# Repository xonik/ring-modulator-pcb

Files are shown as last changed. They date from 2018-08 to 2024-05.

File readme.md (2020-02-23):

# Yusynth Ring modulator

http://yusynth.net/Modular/EN/RINGMOD/index.html

All text is from Yusynth

## Description

The balanced modulator or four quadrant multiplier, is a great classical module. it provides the same functions as those of a ring modulator. Its main purpose is to generate  sounds with a complex overtone content such as bell sounds and other klang tones !
The principle of this circuit is based on a Gilbert cell (see references at the end of this page) contained in the classical LM1496 IC.

Basically, if one feeds the A input with a sinewave with frequency f1, that is sin(2πf1), and the B input with a sinewave with frequenc f2, that is sin(2πf2), one gets at the output the product these two signals, that is sin(2πf1) x sin(2πf2).

Due to trigonomic properties it reads :

 sin(2πf1) x sin(2πf2) = sin(2π(f1+f2)) + sin(2π(f1-f2))

in other words the output is a mixture of two sinewaves, one with frequency f1+f2 and the other with frequency f1-f2.

## Schematic

The schematic of this balanced modulator is directly inspired by that of the Elektor's Formant  (which is a mere adaptation of the application schematic of the LM1496 datasheet, see at the end of this page). I have only changed the values of the input resistors in order to make the input signal levels compatible with the Moog/Dotcom standards (10V peak to peak) I also added an output stage that amplifies the output signal by 6.8 in order to obtain 10Vpp.

## Settings and trimming

There are four trimmers to adjust : A1 to A4. These trimmers are used for cancelling the input signals. The settings are quite simple, you will need a signal generator that delivers a sinewave signal with a 10V (peak to peak) output amplitude. Here is how to proceed :
Tune the generator on 1000Hz and set the output level of the generator to 10Vpp.

Connect the output AxB (or CxD) of the module to an audio amplifier. Be sure to set the input potentiometer of the amplifier to a low value : the output level of the module is 10Vpp and most of the audio amplifiers expect an input level that doesn't exceed 1Vpp.
Connect the signal generator to the input A (or C) with a capacitor (AC-INPUT). There, you must hxear the 1000Hz signal at the output AxB (or CxD).

Adjust the trimmer A2 (or A4) such that the 1000Hz signal can no longer be heard at the output.

Disconnect the signal generator from input A (or C) and then connect the signal generator to the input B (or D)  with a capacitor (AC-INPUT). There, you must hear the 1000Hz signal at the output AxB (or CxD).
Adjust the trimmer A1 (or A3) such that the 1000Hz signal can no longer be heard at the output.

Now the module is ready to operate. A last check can be done by connecting the 1000Hz signal to both inputs A and B (AC inputs) : there you must hear a single signal of frequency twice as high (2000Hz).

**Comment (JT): A1 and A3 are the 470/500 ohm pots, A2 and A4 are 200/220 ohm.**

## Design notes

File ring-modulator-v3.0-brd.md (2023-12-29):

# ring-modulator-v3.0

### Board top
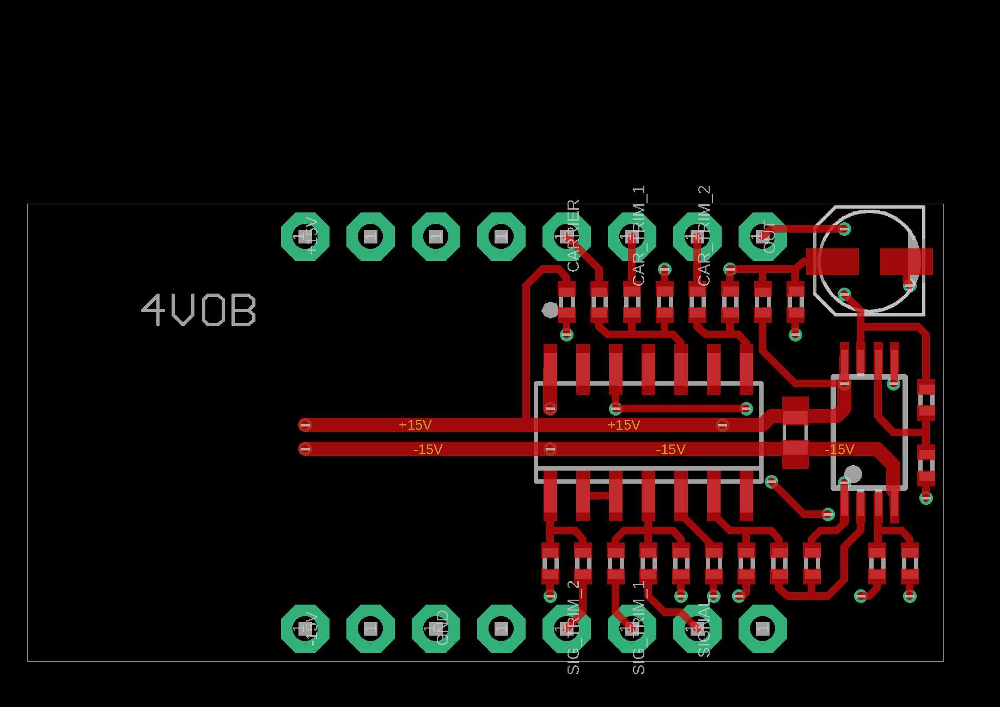
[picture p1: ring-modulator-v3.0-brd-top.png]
Top side

### Board bottom
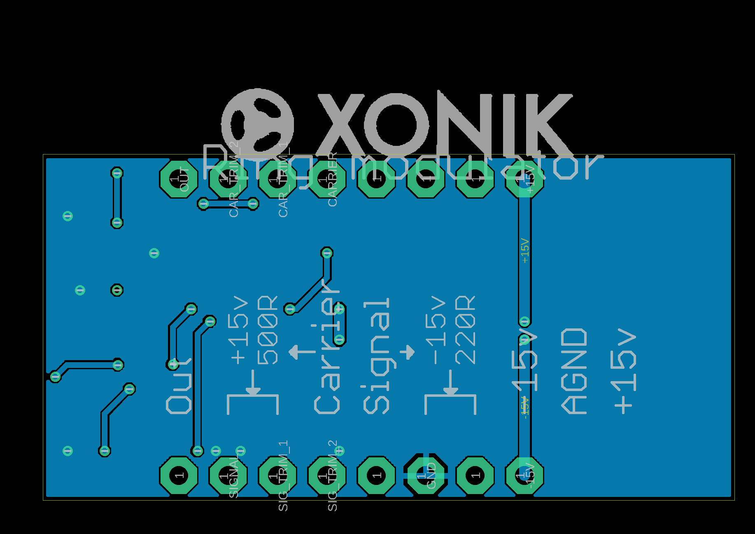
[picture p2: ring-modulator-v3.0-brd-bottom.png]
Bottom side


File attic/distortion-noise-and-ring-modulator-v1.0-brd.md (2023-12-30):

# distortion-noise-and-ring-modulator-v1.0

### Board top
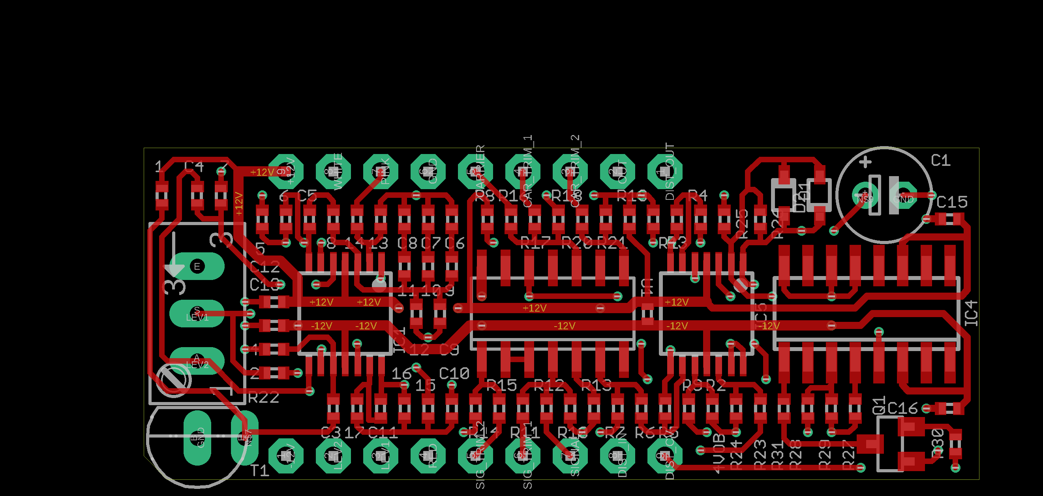
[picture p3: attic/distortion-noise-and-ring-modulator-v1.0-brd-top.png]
Top side

### Board bottom
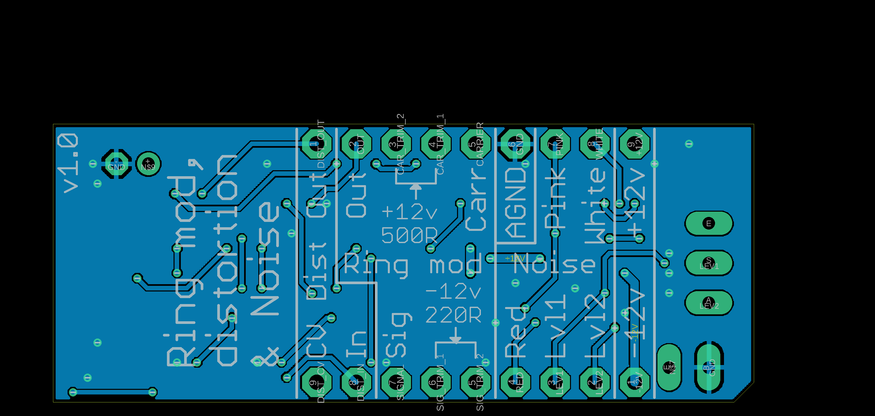
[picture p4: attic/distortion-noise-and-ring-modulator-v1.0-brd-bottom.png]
Bottom side


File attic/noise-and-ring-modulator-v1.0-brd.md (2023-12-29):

# noise-and-ring-modulator-v1.0

### Board top
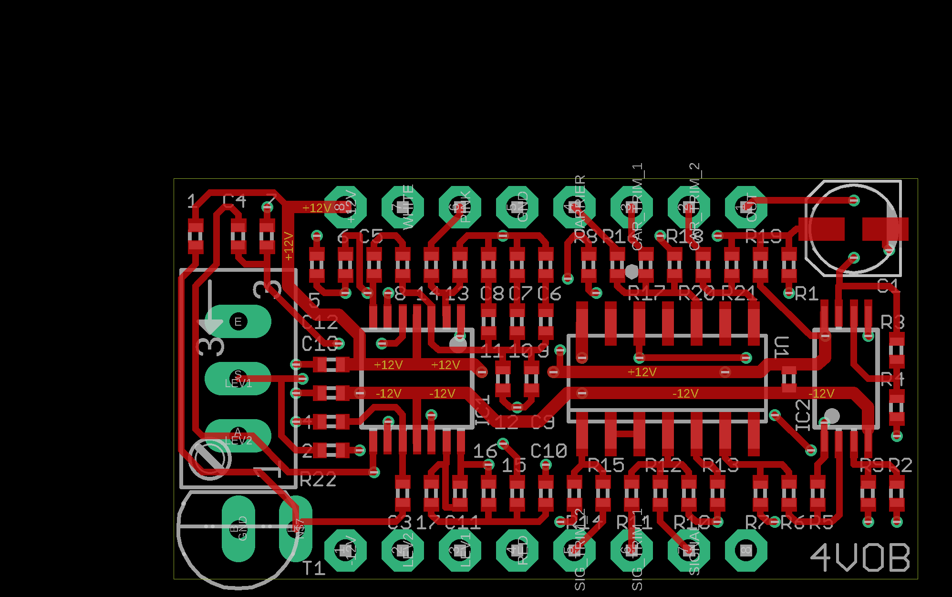
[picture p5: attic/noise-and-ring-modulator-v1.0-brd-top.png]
Top side

### Board bottom
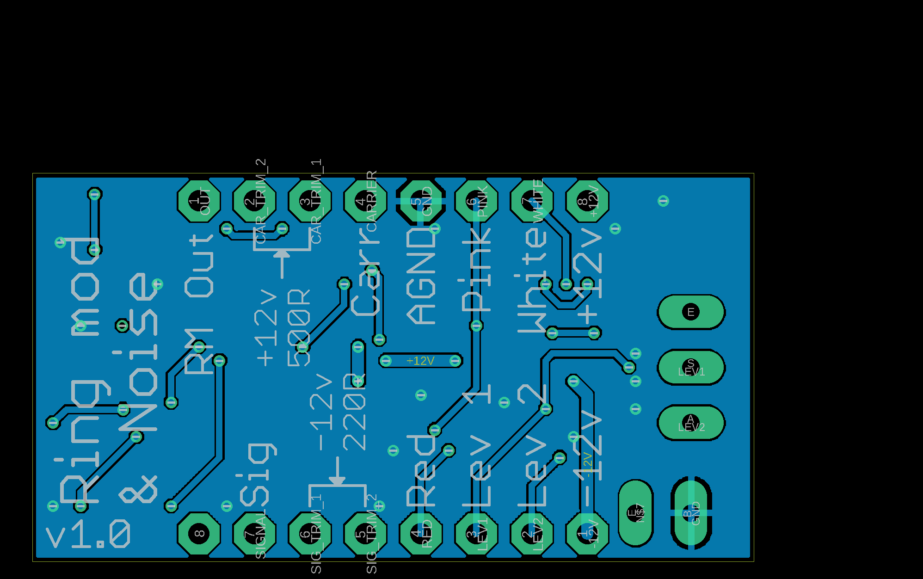
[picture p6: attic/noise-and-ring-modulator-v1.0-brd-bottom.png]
Bottom side


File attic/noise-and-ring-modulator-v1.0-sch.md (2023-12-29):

# noise-and-ring-modulator-v1.0

### Sheet 1

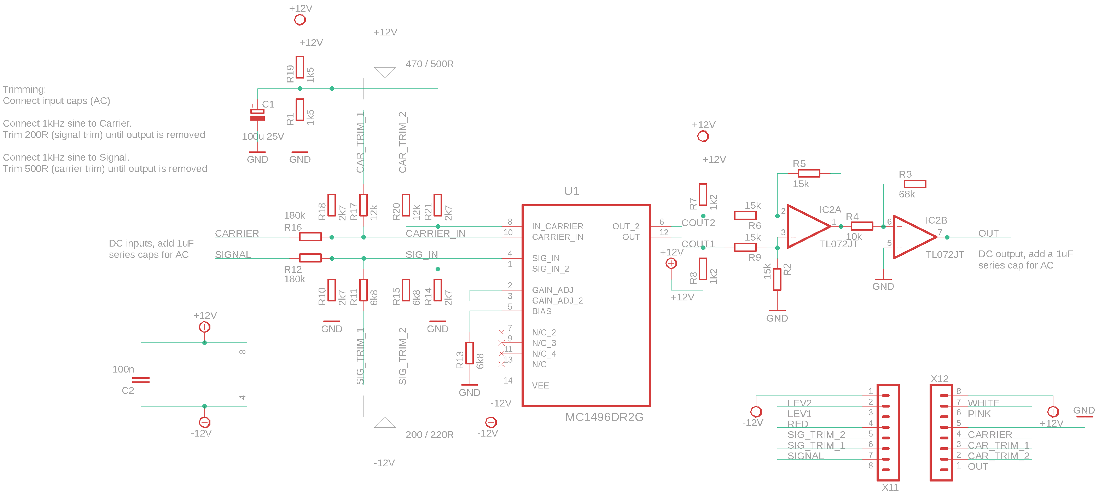
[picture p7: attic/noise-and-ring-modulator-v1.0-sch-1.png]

### Sheet 2

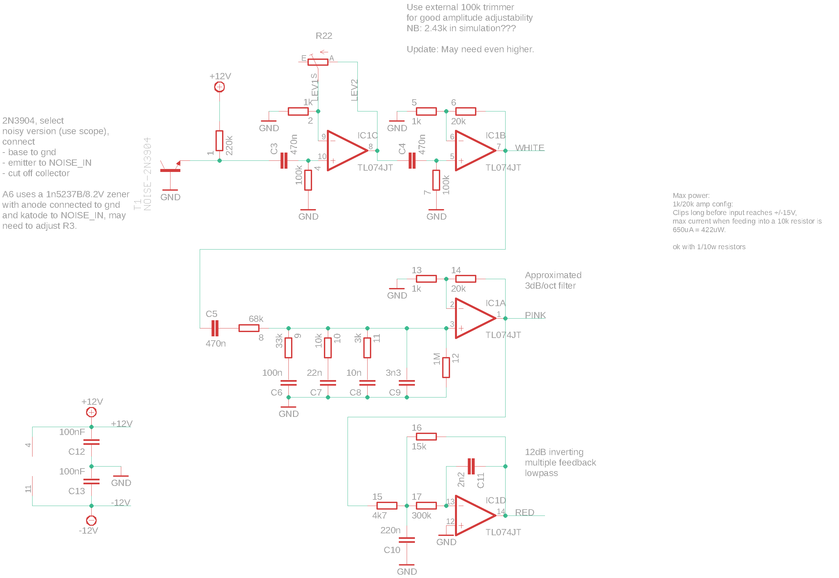
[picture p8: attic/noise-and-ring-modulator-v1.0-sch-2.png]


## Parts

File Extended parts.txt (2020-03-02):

Extended parts, ring modulator
100u
MC1496

Missing in bom:
IC1, TL072

Wrong direction:
U1 is 90, should be 0
C1 is 90 should be 270 (wrong polarity)

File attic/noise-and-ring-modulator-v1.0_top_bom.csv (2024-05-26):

Comment | Designator | Footprint | LCSC Part #
MA08N-1J | X11 X12 | MA08N-1J
1M | 12 | R0402
1k | 2 5 13 | R0402
1k2 | R7 R8 | R0402
1k5 | R1 R19 | R0402
2k7 | R10 R14 R18 R21 | R0402
2n2 | C11 | C0402-J
3k | 11 | R0402
3n3 | C9 | C0402-J
4k7 | 15 | R0402
6k8 | R11 R13 R15 | R0402
10k | 10 R4 | R0402
10n | C8 | C0402-J
12k | R17 R20 | R0402
15k | 16 R2 R5 R6 R9 | R0402
20k | 6 14 | R0402
22n | C7 | C0402-J
33k | 9 | R0402
68k | 8 R3 | R0402
100k | 4 7 | R0402
100n | C2 C6 | C0402-J
100nF | C12 C13 | C0402-J
100u 25V | C1 | UD-4X5 | 8_NICHICON
180k | R12 R16 | R0402
200k | R22 | S64W
220k | 1 | R0402
220n | C10 | C0402-J
300k | 17 | R0402
470n | C3 C4 C5 | C0402-J
MC1496DR2G | U1 | SOIC127P600X175-14N
NOISE-2N3904 | T1 | NOISE-2N3904-J
TL072JT | IC2 | TSSOP8J
TL074JT | IC1 | TSSOP14J

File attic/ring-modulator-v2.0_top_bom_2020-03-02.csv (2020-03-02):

Comment | Designator | Footprint | LCSC Part #
1k2 | R7 R8 | R0805 | C17379
1k5 | R1 R19 | R0805 | C4310
2k7 | R10 R14 R18 R21 | R0805 | C17530
6k8 | R11 R13 R15 | R0805 | C17772
10k | R4 | R0805 | C17414
12k | R17 R20 | R0805 | C17444
15k | R2 R5 R6 R9 | R0805 | C17475
68k | R3 | R0805 | C17801
100n | C2 | C0603 | C14663
100u 25V | C1 | CAPAE660X610N | C176675
180k | R12 R16 | R0805 | C17501
MC1496DR2G | U1 | SOIC127P600X175-14N | C7295
TL072 | IC1 | SO08 | C6961

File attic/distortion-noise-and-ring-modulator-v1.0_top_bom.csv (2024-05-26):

Comment | Designator | Footprint | LCSC Part #
MA09N-1J | X2 X3 | MA09N-1J
1M | 12 | R0402
1N4148 | D1 D2 | SOD323J
1k | 2 5 13 R24 R25 | R0402
1k2 | R7 R8 | R0402
1k5 | R1 R19 | R0402
2k7 | R10 R14 R18 R21 | R0402
2n2 | C11 | C0402-J
3k | 11 | R0402
3n3 | C9 | C0402-J
4k7 | 15 | R0402
6k8 | R11 R13 R15 | R0402
8k2 | R30 | R0402
10k | 10 R4 R31 | R0402
10n | C8 | C0402-J
12k | R17 R20 | R0402
15k | 16 R2 R5 R6 R9 R28 | R0402
20k | 6 14 | R0402
22n | C7 | C0402-J
33k | 9 R23 R26 | R0402
68k | 8 R3 | R0402
100k | 4 7 | R0402
100n | C2 C6 | C0402-J
100nF | C12 C13 C15 C16 | C0402-J
100u 25V | C1 | E2-5
180k | R12 R16 | R0402
200k | R22 | S64W
220k | 1 | R0402
220n | C10 | C0402-J
300k | 17 | R0402
470n | C3 C4 C5 | C0402-J
510R | R27 R29 | R0402
LM13700SL | IC4 | SO16-NARROW-J
MC1496DR2G | U1 | SOIC127P600X175-14N
MMBT3906 | Q1 | SOT23-BEC
NOISE-2N3904 | T1 | NOISE-2N3904-J
TL074JT | IC1 IC5 | TSSOP14J

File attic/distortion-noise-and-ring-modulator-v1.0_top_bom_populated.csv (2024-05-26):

Comment | Designator | Footprint | LCSC Part #
MA09N-1J | X2 X3 | MA09N-1J | undefined
1M | 12 | R0402 | C327799
1N4148 | D1 D2 | SOD323J | C2128
1k | 2 5 13 R24 R25 | R0402 | C11702
1.2k | R7 R8 | R0402 | C413082
1.5k | R1 R19 | R0402 | C25867
2.7k | R10 R14 R18 R21 | R0402 | C416505
2.2n | C11 | C0402 | C2987940
3k | 11 | R0402 | C278590
3.3n | C9 | C0402 | C1518207
4.7k | 15 | R0402 | C25900
6.8k | R11 R13 R15 | R0402 | C323629
8.2k | R30 | R0402 | C25946
10k | 10 R4 R31 | R0402 | C25744
10n | C8 | C0402 | C3855387
12k | R17 R20 | R0402 | C25752
15k | 16 R2 R5 R6 R9 R28 | R0402 | C25756
20k | 6 14 | R0402 | C25765
22n | C7 | C0402 | C5137627
33k | 9 R23 R26 | R0402 | C25779
68k | 8 R3 | R0402 | C36871
100k | 4 7 | R0402 | C25741
100n | C2 C6 | C0402 | C307331
100n | C12 C13 C15 C16 | C0402 | C307331
100u 25V | C1 | E2-5 | C47873
180k | R12 R16 | R0402 | C323674
200k | R22 | S64W | C118942
220k | 1 | R0402 | C25767
220n | C10 | C0402 | C2992619
300k | 17 | R0402 | C413115
470n | C3 C4 C5 | C0402 | C437527
510R | R27 R29 | R0402 | C25123
LM13700SL | IC4 | SO16-NARROW-J | C174050
MC1496DR2G | U1 | SO14 | C7295
MMBT3906 | Q1 | SOT23-BEC | C2143
NOISE-2N3904 | T1 | NOISE-2N3904-J | undefined
TL074JT | IC1 IC5 | TSSOP14 | C2652279

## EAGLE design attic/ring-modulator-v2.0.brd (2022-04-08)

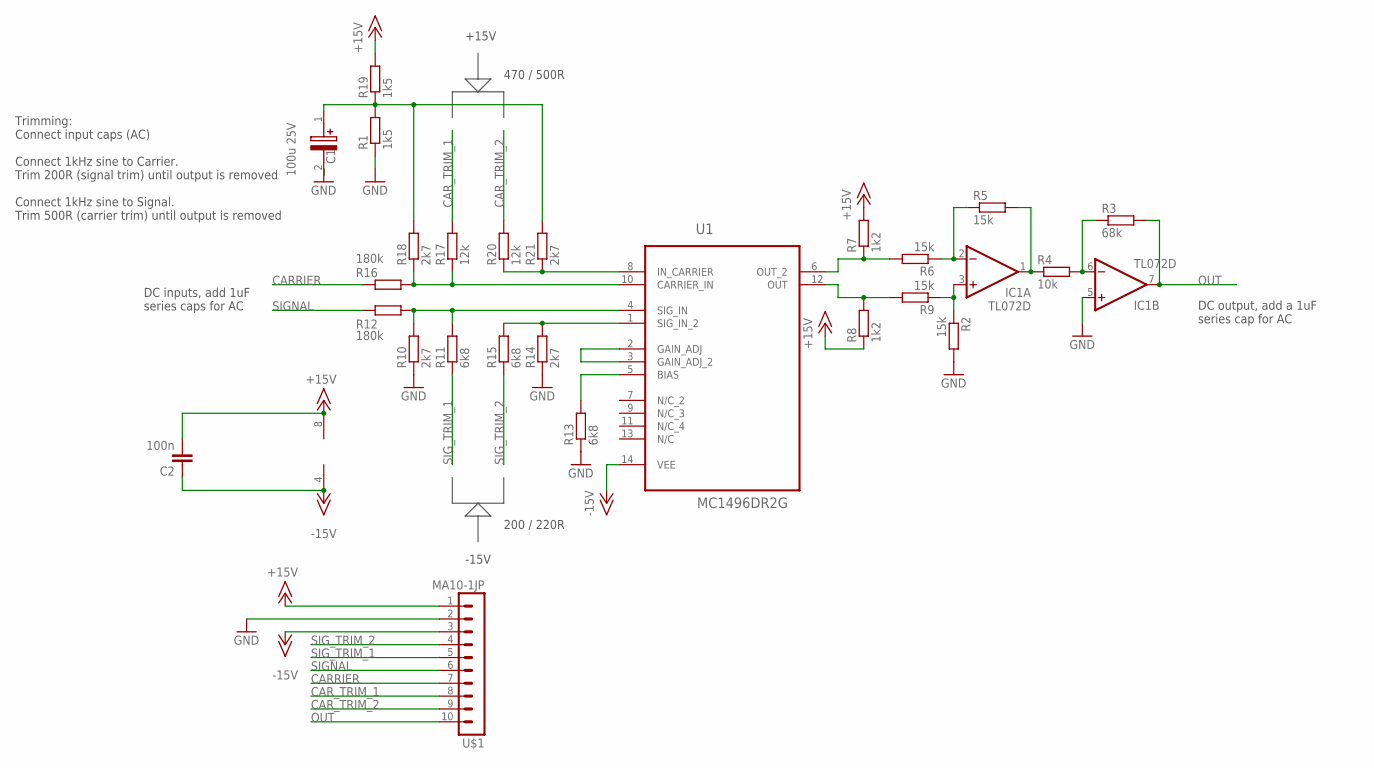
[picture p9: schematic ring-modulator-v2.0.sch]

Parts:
C1: 100u 25V; CAPAE660X610N
C2: 100n; C0603
IC1: TL072D; SO08J
R1, R19: 1k5; R0805
R2, R5, R6, R9: 15k; R0805
R3: 68k; R0805
R4: 10k; R0805
R7, R8: 1k2; R0805
R10, R14, R18, R21: 2k7; R0805
R11, R13, R15: 6k8; R0805
R12, R16: 180k; R0805
R17, R20: 12k; R0805
U1: MC1496DR2G; SOIC127P600X175-14N
U$1: MA10-1JP; SIP-PIN10-1J

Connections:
+15V: C2.2, IC1.8 (V+), R7.2, R8.1, R19.2, U$1.1
-15V: C2.1, IC1.4 (V-), U1.14 (VEE), U$1.3
CARRIER: R16.1, U$1.7
CAR_TRIM_1: R17.2, U$1.8
CAR_TRIM_2: R20.2, U$1.9
GND: C1.2 (-), IC1.5 (+IN), R1.1, R2.2, R10.1, R13.1, R14.1, U$1.2
unnamed: R10.2, R11.2, R12.2, U1.4 (SIG_IN)
unnamed: R16.2, R17.1, R18.1, U1.10 (CARRIER_IN)
unnamed: R14.2, R15.2, U1.1 (SIG_IN_2)
unnamed: R20.1, R21.1, U1.8 (IN_CARRIER)
unnamed: C1.1 (+), R1.2, R18.2, R19.1, R21.2
unnamed: R13.2, U1.5 (BIAS)
unnamed: U1.2 (GAIN_ADJ), U1.3 (GAIN_ADJ_2)
unnamed: R6.2, R7.1, U1.6 (OUT_2)
unnamed: R8.2, R9.2, U1.12 (OUT)
unnamed: IC1.3 (+IN), R2.1, R9.1
unnamed: IC1.2 (-IN), R5.1, R6.1
unnamed: IC1.1 (OUT), R4.1, R5.2
unnamed: IC1.6 (-IN), R3.1, R4.2
OUT: IC1.7 (OUT), R3.2, U$1.10
SIGNAL: R12.1, U$1.6
SIG_TRIM_1: R11.1, U$1.5
SIG_TRIM_2: R15.1, U$1.4

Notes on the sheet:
470 / 500R
+15V
200 / 220R
-15V
DC inputs, add 1uF series caps for AC
DC output, add a 1uF series cap for AC
Trimming: Connect input caps (AC) Connect 1kHz sine to Carrier. Trim 200R (signal trim) until output is removed Connect 1kHz sine to Signal. Trim 500R (carrier trim) until output is removed

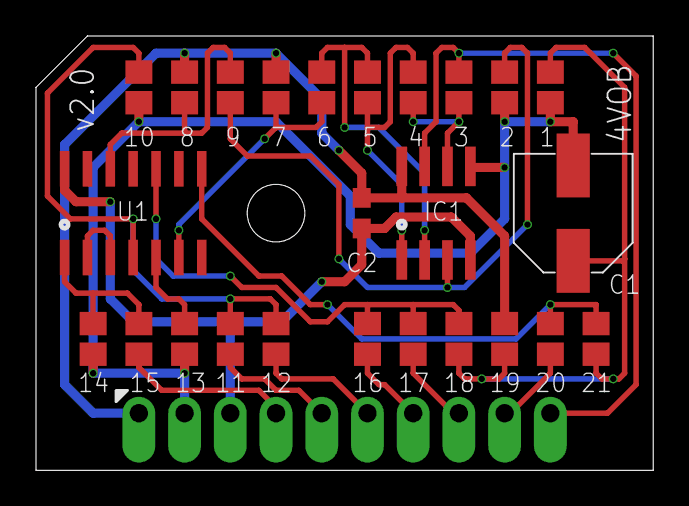
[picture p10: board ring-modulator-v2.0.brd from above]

Board: 2 copper layers, 34.3 x 24.1 mm, 27 parts (1 on the bottom side), 23 nets.

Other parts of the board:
U$3: XONIK_LOGO_18

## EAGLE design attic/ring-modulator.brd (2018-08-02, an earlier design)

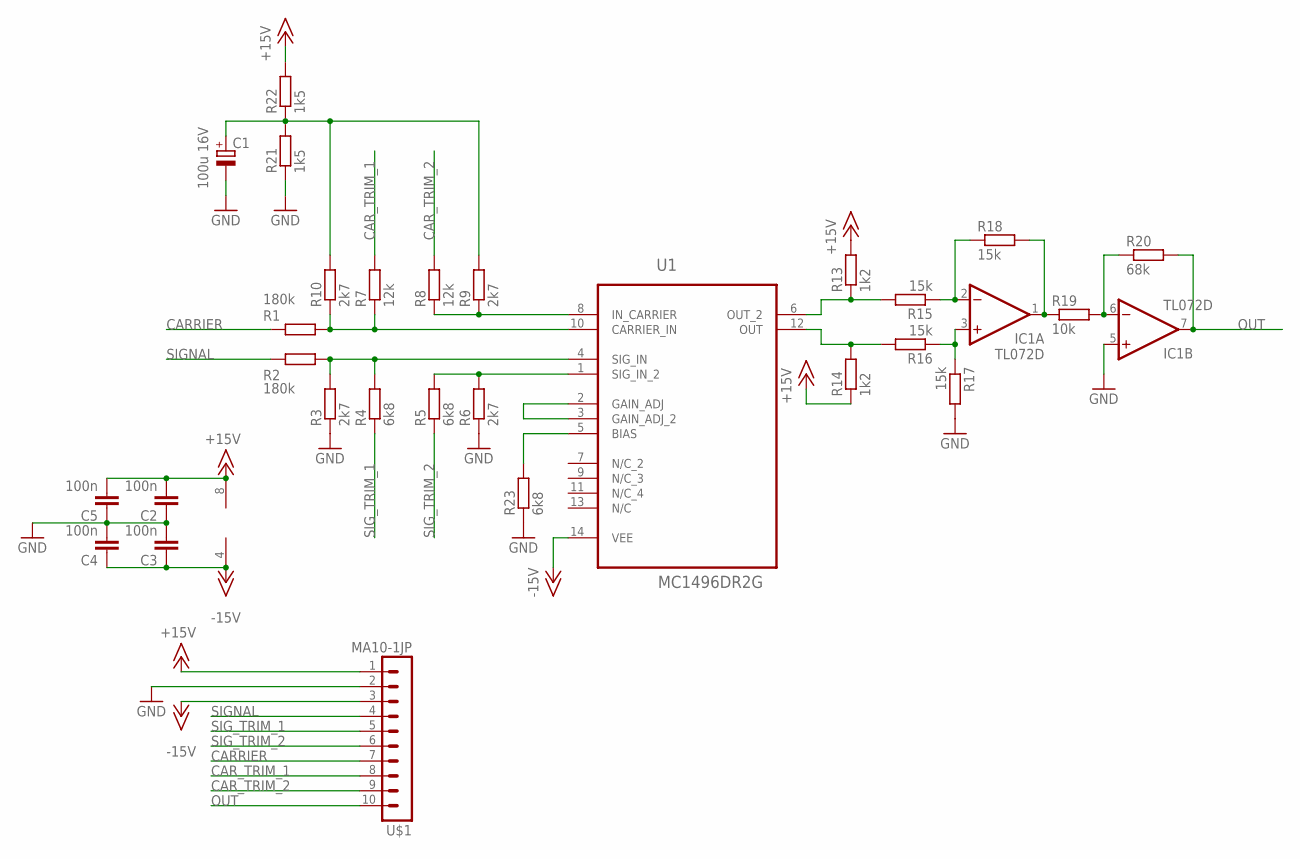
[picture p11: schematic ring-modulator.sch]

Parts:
C1: 100u 16V; E2,5-5
C2, C3, C4, C5: 100n; C0805
IC1: TL072D; SO08J
R1, R2: 180k; R0805
R3, R6, R9, R10: 2k7; R0805
R4, R5, R23: 6k8; R0805
R7, R8: 12k; R0805
R13, R14: 1k2; R0805
R15, R16, R17, R18: 15k; R0805
R19: 10k; R0805
R20: 68k; R0805
R21, R22: 1k5; R0805
U1: MC1496DR2G; SOIC127P600X175-14N
U$1: MA10-1JP; SIP-PIN10-1J

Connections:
+15V: C2.2, C5.2, IC1.8 (V+), R13.2, R14.1, R22.2, U$1.1
-15V: C3.1, C4.1, IC1.4 (V-), U1.14 (VEE), U$1.3
CARRIER: R1.1, U$1.7
CAR_TRIM_1: R7.2, U$1.8
CAR_TRIM_2: R8.2, U$1.9
GND: C1.-, C2.1, C3.2, C4.2, C5.1, IC1.5 (+IN), R3.1, R6.1, R17.2, R21.1, R23.1, U$1.2
unnamed: R2.2, R3.2, R4.2, U1.4 (SIG_IN)
unnamed: R1.2, R7.1, R10.1, U1.10 (CARRIER_IN)
unnamed: R5.2, R6.2, U1.1 (SIG_IN_2)
unnamed: R8.1, R9.1, U1.8 (IN_CARRIER)
unnamed: C1.+, R9.2, R10.2, R21.2, R22.1
unnamed: R23.2, U1.5 (BIAS)
unnamed: U1.2 (GAIN_ADJ), U1.3 (GAIN_ADJ_2)
unnamed: R13.1, R15.2, U1.6 (OUT_2)
unnamed: R14.2, R16.2, U1.12 (OUT)
unnamed: IC1.3 (+IN), R16.1, R17.1
unnamed: IC1.2 (-IN), R15.1, R18.1
unnamed: IC1.1 (OUT), R18.2, R19.1
unnamed: IC1.6 (-IN), R19.2, R20.1
OUT: IC1.7 (OUT), R20.2, U$1.10
SIGNAL: R2.1, U$1.4
SIG_TRIM_1: R4.1, U$1.5
SIG_TRIM_2: R5.1, U$1.6

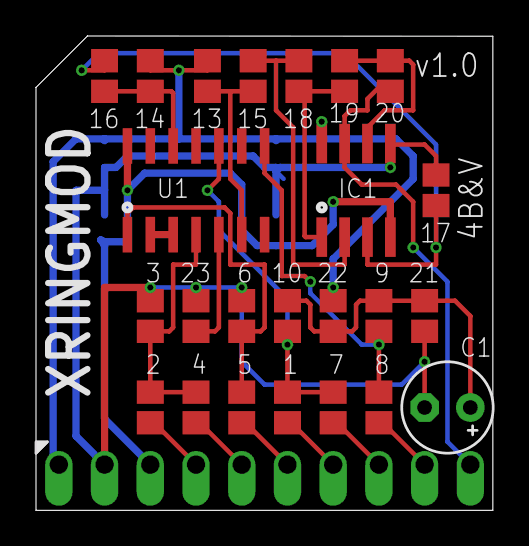
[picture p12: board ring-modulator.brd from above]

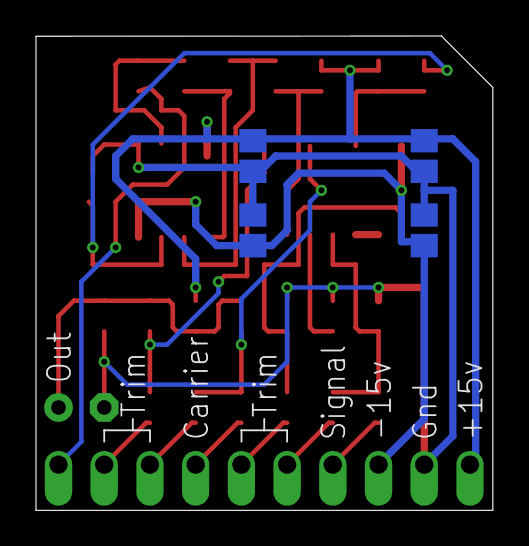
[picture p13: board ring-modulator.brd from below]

Board: 2 copper layers, 25.4 x 26.4 mm, 29 parts (4 on the bottom side), 23 nets.

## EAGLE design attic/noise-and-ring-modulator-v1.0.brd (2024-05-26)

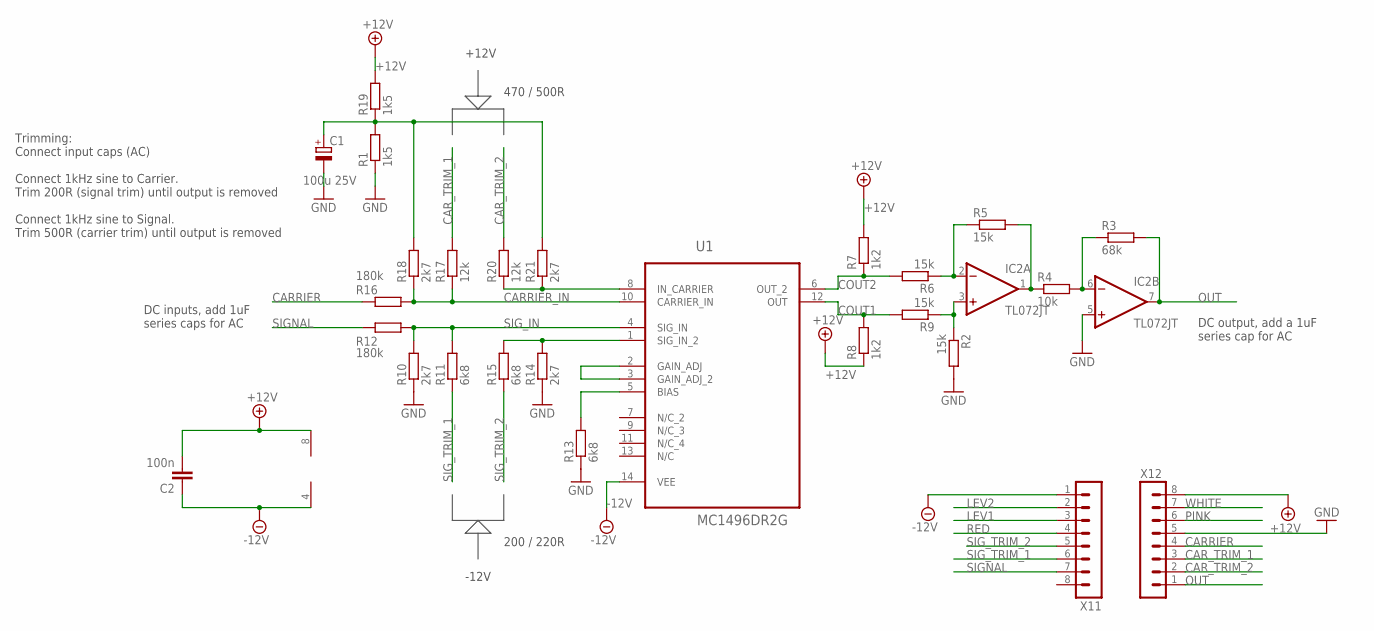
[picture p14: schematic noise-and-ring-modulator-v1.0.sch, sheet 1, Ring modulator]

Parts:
C1: 100u 25V; UD-4X5,8_NICHICON
C2: 100n; C0402-J
IC2: TL072JT; TSSOP8J
R1, R19: 1k5; R0402
R2, R5, R6, R9: 15k; R0402
R3: 68k; R0402
R4: 10k; R0402
R7, R8: 1k2; R0402
R10, R14, R18, R21: 2k7; R0402
R11, R13, R15: 6k8; R0402
R12, R16: 180k; R0402
R17, R20: 12k; R0402
U1: MC1496DR2G; SOIC127P600X175-14N
X11, X12: MA08-1JN; MA08N-1J

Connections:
+12V: C2.2, IC2.8 (V+), R7.2, R8.1, R19.2, X12.8; also elsewhere on the board
-12V: C2.1, IC2.4 (V-), U1.14 (VEE), X11.1; also elsewhere on the board
CARRIER: R16.1, X12.4
CARRIER_IN: R16.2, R17.1, R18.1, U1.10 (CARRIER_IN)
CAR_TRIM_1: R17.2, X12.3
CAR_TRIM_2: R20.2, X12.2
COUT1: R8.2, R9.2, U1.12 (OUT)
COUT2: R6.2, R7.1, U1.6 (OUT_2)
GND: C1.-, IC2.5 (+IN), R1.1, R2.2, R10.1, R13.1, R14.1, X12.5; also elsewhere on the board
LEV1: X11.3; also elsewhere on the board
LEV2: X11.2; also elsewhere on the board
unnamed: R14.2, R15.2, U1.1 (SIG_IN_2)
unnamed: R20.1, R21.1, U1.8 (IN_CARRIER)
unnamed: C1.+, R1.2, R18.2, R19.1, R21.2
unnamed: R13.2, U1.5 (BIAS)
unnamed: U1.2 (GAIN_ADJ), U1.3 (GAIN_ADJ_2)
unnamed: IC2.3 (+IN), R2.1, R9.1
unnamed: IC2.2 (-IN), R5.1, R6.1
unnamed: IC2.1 (OUT), R4.1, R5.2
unnamed: IC2.6 (-IN), R3.1, R4.2
OUT: IC2.7 (OUT), R3.2, X12.1
PINK: X12.6; also elsewhere on the board
RED: X11.4; also elsewhere on the board
SIGNAL: R12.1, X11.7
SIG_IN: R10.2, R11.2, R12.2, U1.4 (SIG_IN)
SIG_TRIM_1: R11.1, X11.6
SIG_TRIM_2: R15.1, X11.5
WHITE: X12.7; also elsewhere on the board

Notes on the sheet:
470 / 500R
+12V
200 / 220R
-12V
DC inputs, add 1uF series caps for AC
DC output, add a 1uF series cap for AC
Trimming: Connect input caps (AC) Connect 1kHz sine to Carrier. Trim 200R (signal trim) until output is removed Connect 1kHz sine to Signal. Trim 500R (carrier trim) until output is removed

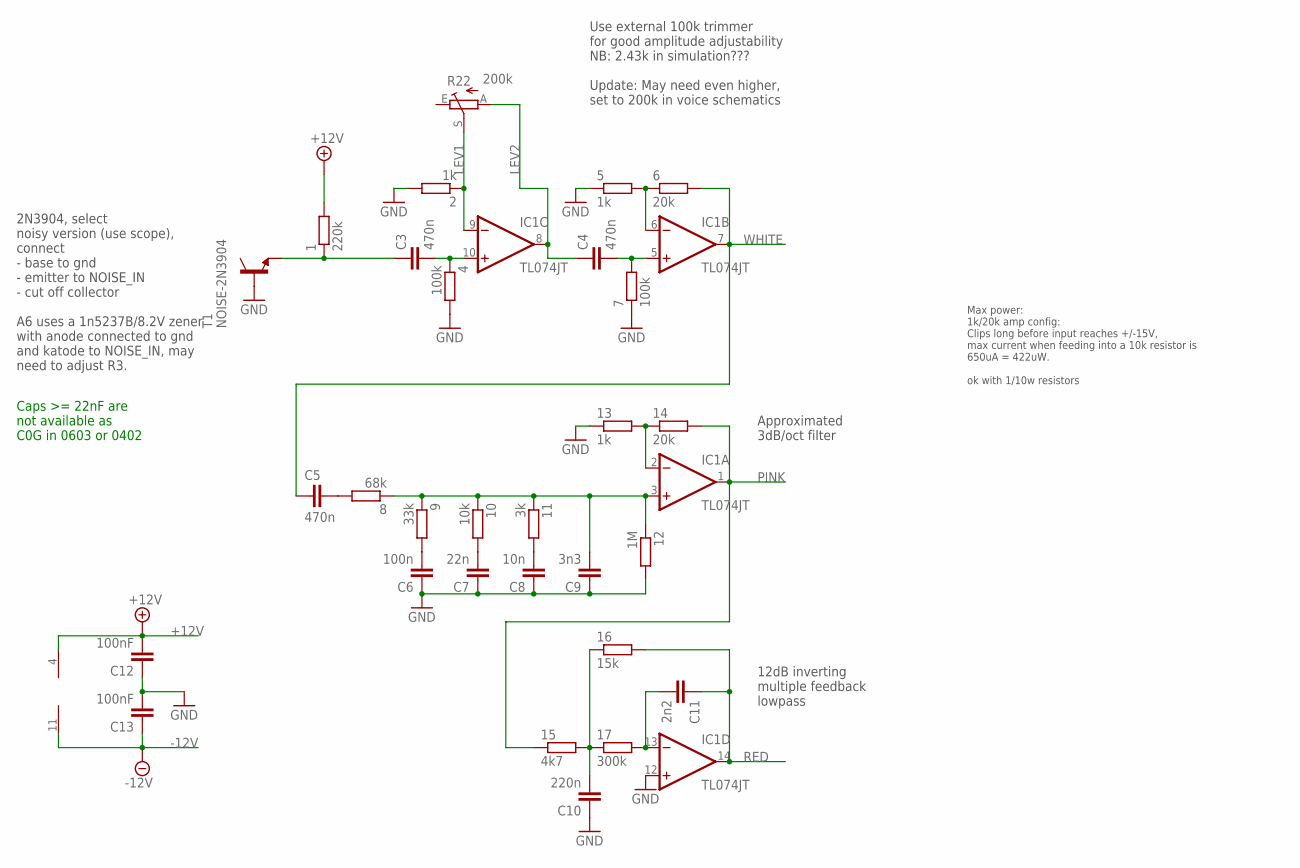
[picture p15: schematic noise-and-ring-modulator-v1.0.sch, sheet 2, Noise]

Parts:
1: 220k; R0402
2, 5, 13: 1k; R0402
4, 7: 100k; R0402
6, 14: 20k; R0402
8: 68k; R0402
9: 33k; R0402
10: 10k; R0402
11: 3k; R0402
12: 1M; R0402
15: 4k7; R0402
16: 15k; R0402
17: 300k; R0402
C3, C4, C5: 470n; C0402-J
C6: 100n; C0402-J
C7: 22n; C0402-J
C8: 10n; C0402-J
C9: 3n3; C0402-J
C10: 220n; C0402-J
C11: 2n2; C0402-J
C12, C13: 100nF; C0402-J
IC1: TL074JT; TSSOP14J
R22: 200k; S64W
T1: NOISE-2N3904; NOISE-2N3904-J

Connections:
+12V: 1.2, C12.2, IC1.4 (V+); also elsewhere on the board
-12V: C13.1, IC1.11 (V-); also elsewhere on the board
GND: 2.2, 4.2, 5.1, 7.1, 12.2, 13.1, C6.1, C7.1, C8.1, C9.1, C10.1, C12.1, C13.2, IC1.12 (+IN), T1.B; also elsewhere on the board
LEV1: 2.1, IC1.9 (-IN), R22.S; also elsewhere on the board
LEV2: C4.1, IC1.8 (OUT), R22.A; also elsewhere on the board
unnamed: 13.2, 14.1, IC1.2 (-IN)
unnamed: 5.2, 6.1, IC1.6 (-IN)
unnamed: 9.2, C6.2
unnamed: 10.2, C7.2
unnamed: 11.2, C8.2
unnamed: 1.1, C3.1, T1.E
unnamed: 4.1, C3.2, IC1.10 (+IN)
unnamed: 7.2, C4.2, IC1.5 (+IN)
unnamed: 8.1, 9.1, 10.1, 11.1, 12.1, C9.2, IC1.3 (+IN)
unnamed: 8.2, C5.2
unnamed: 15.2, 16.1, 17.1, C10.2
unnamed: 17.2, C11.2, IC1.13 (-IN)
PINK: 14.2, 15.1, IC1.1 (OUT); also elsewhere on the board
RED: 16.2, C11.1, IC1.14 (OUT); also elsewhere on the board
WHITE: 6.2, C5.1, IC1.7 (OUT); also elsewhere on the board

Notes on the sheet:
Use external 100k trimmer for good amplitude adjustability NB: 2.43k in simulation??? Update: May need even higher, set to 200k in voice schematics
Approximated 3dB/oct filter
12dB inverting multiple feedback lowpass
2N3904, select noisy version (use scope), connect - base to gnd - emitter to NOISE_IN - cut off collector A6 uses a 1n5237B/8.2V zener with anode connected to gnd and katode to NOISE_IN, may need to adjust R3.
Max power: 1k/20k amp config: Clips long before input reaches +/-15V, max current when feeding into a 10k resistor is 650uA = 422uW. ok with 1/10w resistors
Caps >= 22nF are not available as C0G in 0603 or 0402

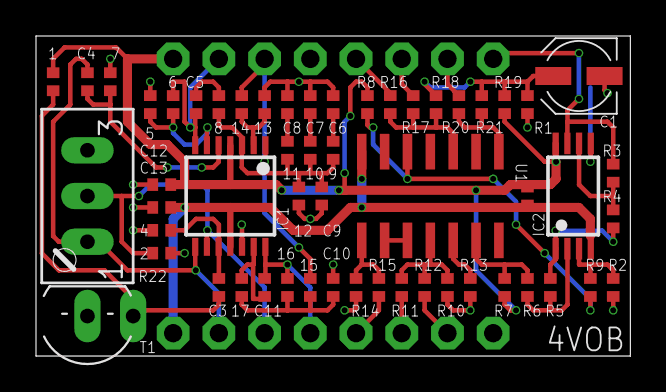
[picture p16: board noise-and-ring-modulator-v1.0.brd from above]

Board: 2 copper layers, 33.0 x 17.8 mm, 57 parts (0 on the bottom side), 40 nets.

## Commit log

2018-07-28 Fully traced ring modulator
    [ring-modulator.brd, ring-modulator.sch]
2018-07-31 Part and connector names
    [ring-modulator.brd]
2018-08-02 Added logo
    [ring-modulator - v logo.brd, ring-modulator - v logo.sch, ring-modulator.brd]
2018-08-07 Redid board to v1.1, only two rows of resistors instead of 3. Feels much better.
    [ring-modulator-v1.1.brd, ring-modulator-v1.1.sch]
2020-02-16 Version 2, new ground plane, corrected entry point for smd resistors++, added screw hole, added smd elec. cap
    [ring-modulator-v2.0.brd, ring-modulator-v2.0.sch]
2020-02-16 Fixed silk screening, only missing xonik logo
    [ring-modulator-v2.0.brd, ring-modulator-v2.0.sch]
2020-02-17 Added vector logo
    [ring-modulator-v1.1.brd, ring-modulator-v2.0.brd]
2020-02-18 Added smd assembly bom etc
    [ring-modulator-v2.0.brd, ring-modulator-v2.0.sch, ring-modulator-v2.0_top_bom.csv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]
2020-02-20 Added info about external trimmers
    [ring-modulator-v2.0.brd, ring-modulator-v2.0.sch]
2020-02-22 Changed to logo-as-component
    [ring-modulator-v2.0.brd]
2020-02-22 Slight silk adjustment
    [ring-modulator-v2.0.brd]
2020-02-23 Added documentation from yusynth.net
    [ring-modulator-v2.0.sch]
2020-03-02 Added updated BOM and gerber
    [ring-modulator-v2.0.brd, ring-modulator-v2.0_top_bom_2020-03-02.csv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]
2023-12-29 v3, trying to fit noise and ringmod on one chip
    [ring-modulator-v3.0.brd, ring-modulator-v3.0.sch]
2023-12-29 V1.0 of combined noise and ringmod module
    [noise-and-ring-modulator-v1.0.brd, noise-and-ring-modulator-v1.0.sch]
2023-12-29 Fixed silk screen noise/ringmod
    [noise-and-ring-modulator-v1.0.brd]
2023-12-29 Tiny silk screen fix
    [noise-and-ring-modulator-v1.0.brd, noise-and-ring-modulator-v1.0.sch]
2023-12-29 Replaced pin footprints
    [noise-and-ring-modulator-v1.0.brd, noise-and-ring-modulator-v1.0.sch]
2023-12-29 removed some silk screen
    [noise-and-ring-modulator-v1.0.brd]
2023-12-30 Combined noise, rm and distortion
    [distortion-noise-and-ring-modulator-v1.0.brd, distortion-noise-and-ring-modulator-v1.0.sch]
2023-12-30 Added bom and checked parts and pcb with JLCPCB
    [distortion-noise-and-ring-modulator-v1.0.brd, distortion-noise-and-ring-modulator-v1.0.sch]
2024-04-14 v1.1 of combined FX module with trimmers onboard
    [distortion-noise-and-ring-modulator-v1.1.brd, distortion-noise-and-ring-modulator-v1.1.sch]
2024-04-14 Removed all external trimmers
    [distortion-noise-and-ring-modulator-v1.1.brd, distortion-noise-and-ring-modulator-v1.1.sch]
2024-04-14 A bit more gnd
    [distortion-noise-and-ring-modulator-v1.1.brd]
2024-04-14 Nude pin headers
    [distortion-noise-and-ring-modulator-v1.1.brd, distortion-noise-and-ring-modulator-v1.1.sch]
2024-04-19 Replaced 100uf electrolytic cap with two ceramic. Changed 200R to 500R pot to get a single extended part
    [distortion-noise-and-ring-modulator-v1.1.brd, distortion-noise-and-ring-modulator-v1.1.sch]
2024-05-18 Changed to 3k3 on pink filter output to save cost with JLCPCB
    [distortion-noise-and-ring-modulator-v1.1.brd, distortion-noise-and-ring-modulator-v1.1.sch]
2024-05-31 Image update
    [distortion-noise-and-ring-modulator-v1.1.brd]
2024-06-02 Tested with JLCPCB
    [distortion-noise-and-ring-modulator-v1.1.brd, distortion-noise-and-ring-modulator-v1.1.sch]
2024-06-03 Fixed 1uF caps
    [distortion-noise-and-ring-modulator-v1.1.brd, distortion-noise-and-ring-modulator-v1.1.sch]
2024-06-04 Removed unused connections
    [distortion-noise-and-ring-modulator-v1.1.sch]
2024-06-06 Replaced several parts with 0603 to be able to use basic parts
    [distortion-noise-and-ring-modulator-v1.1.brd, distortion-noise-and-ring-modulator-v1.1.sch]
2024-06-06 More basic parts
    [distortion-noise-and-ring-modulator-v1.1.brd, distortion-noise-and-ring-modulator-v1.1.sch]
2024-06-21 Rounded corners
    [distortion-noise-and-ring-modulator-v1.1.brd]
2024-06-23 V1.1 ready for production
    [distortion-noise-and-ring-modulator-v1.1.brd, distortion-noise-and-ring-modulator-v1.1.sch]
2024-06-25 Increased via outer diameter
    [distortion-noise-and-ring-modulator-v1.1.brd]
2025-01-01 Moved multi fx to separate repo
    [distortion-noise-and-ring-modulator-v1.1.brd, distortion-noise-and-ring-modulator-v1.1.sch]
